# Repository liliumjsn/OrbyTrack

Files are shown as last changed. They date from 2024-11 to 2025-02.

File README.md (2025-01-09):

<p align="center">
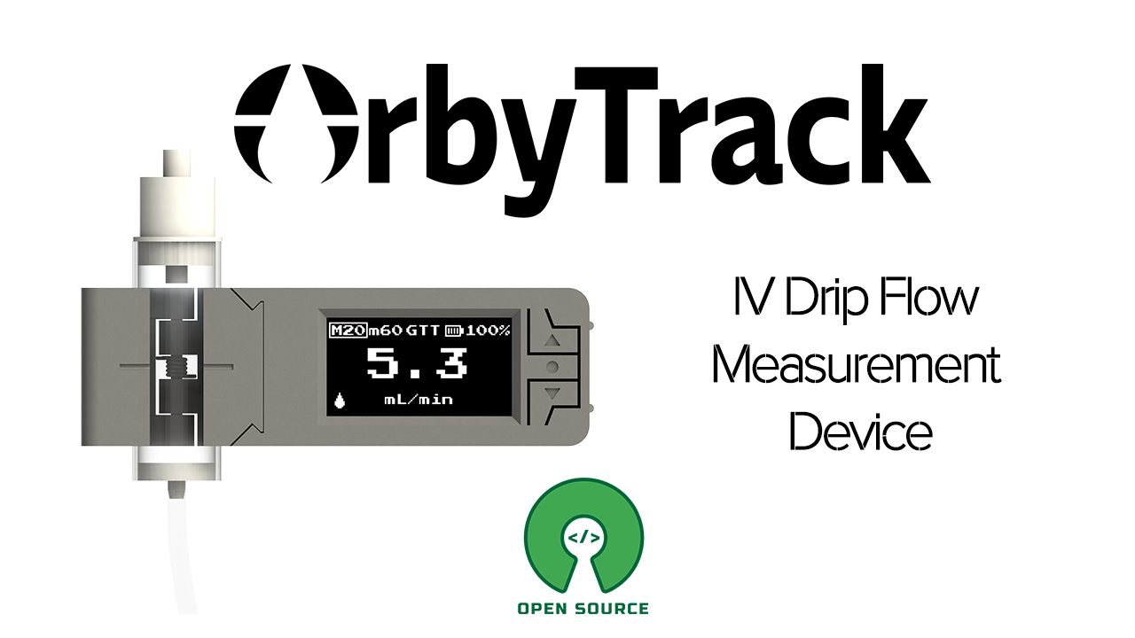
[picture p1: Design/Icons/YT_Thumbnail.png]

</p>

  
  

**OrbyTrack** is a portable, battery-operated device designed to measure the flow rate of an IV drip. Built using the Adafruit Feather M0 module, Adafruit OLED (128x64), and IR-based emitter-receiver drop detection, it provides healthcare professionals with a compact and efficient solution. For nurses working in high-pressure environments such as intensive care units or emergency rooms, OrbyTrack ensures accurate, real-time monitoring of IV flow rates. This accuracy is vital in life-critical moments, helping to prevent over-infusion or under-infusion of fluids, which could have severe consequences for patient outcomes. By providing clear and precise data, OrbyTrack empowers nurses to make informed decisions swiftly and confidently, ensuring patient safety remains the top priority. 

## Features  

- **Accurate Flow Measurement:** IR-based technology for precise IV drip monitoring.  
- **Portable and Battery-Operated:** With 500mAh battery, it can provide 20 hours of continuous usage.  
- **User-Friendly Interface:** Simple control with three tactile buttons and visible screen.  
- **Customizable:** Fully 3D-printable casing.  

## Project Structure  

```markdown
OrbyTrack/  
│  
├── Firmware/     # Codebase for Adafruit Feather M0  
├── Design/       # 3D design files for the casing  
├── Assembly/     # Step-by-step assembly instructions  
└── Usage/        # User guide, calibration, and troubleshooting 
```

## Hardware Overview  

| **Component** | **Details** |  
|---|---|
| Microcontroller | Atmel SAMD21 |  
| Module | Adafruit M0 | 
| Display | Adafruit OLED (128x64) |  
| Buttons | 3 tactile buttons |  
| Sensors | IR emitter-receiver  |  
| Power Source | Battery-operated (500mAh) |  

## License  

This project is licensed under the MIT License. See the `LICENSE` file for details.

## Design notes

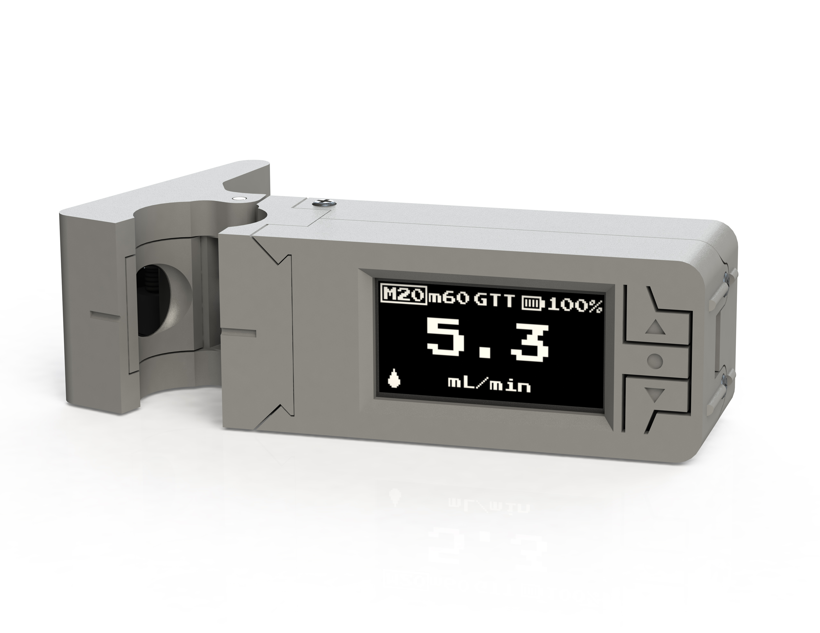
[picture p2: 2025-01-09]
Design/Renders/render_3.jpg

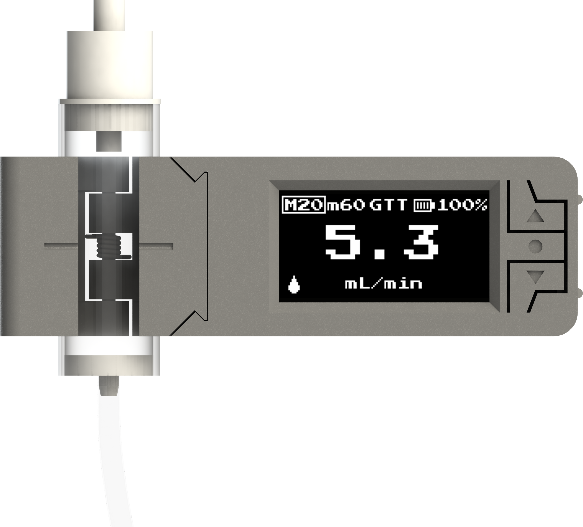
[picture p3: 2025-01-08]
Design/Renders/render_1.png

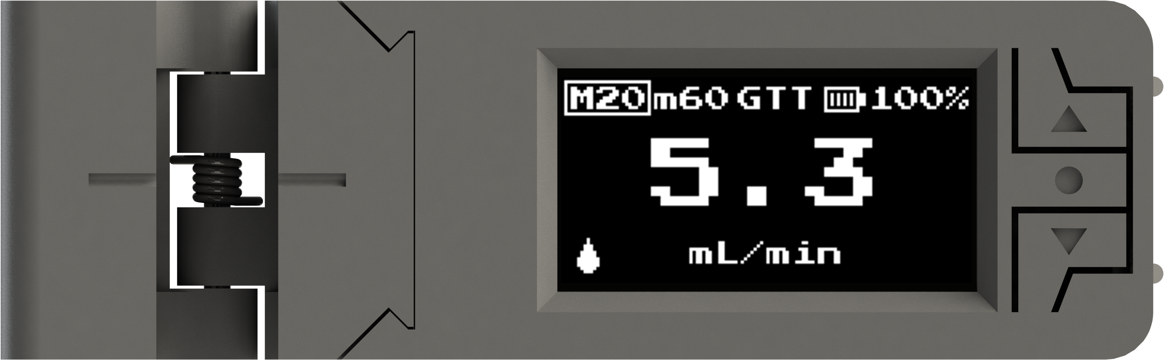
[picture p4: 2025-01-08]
Design/Renders/render_2.png

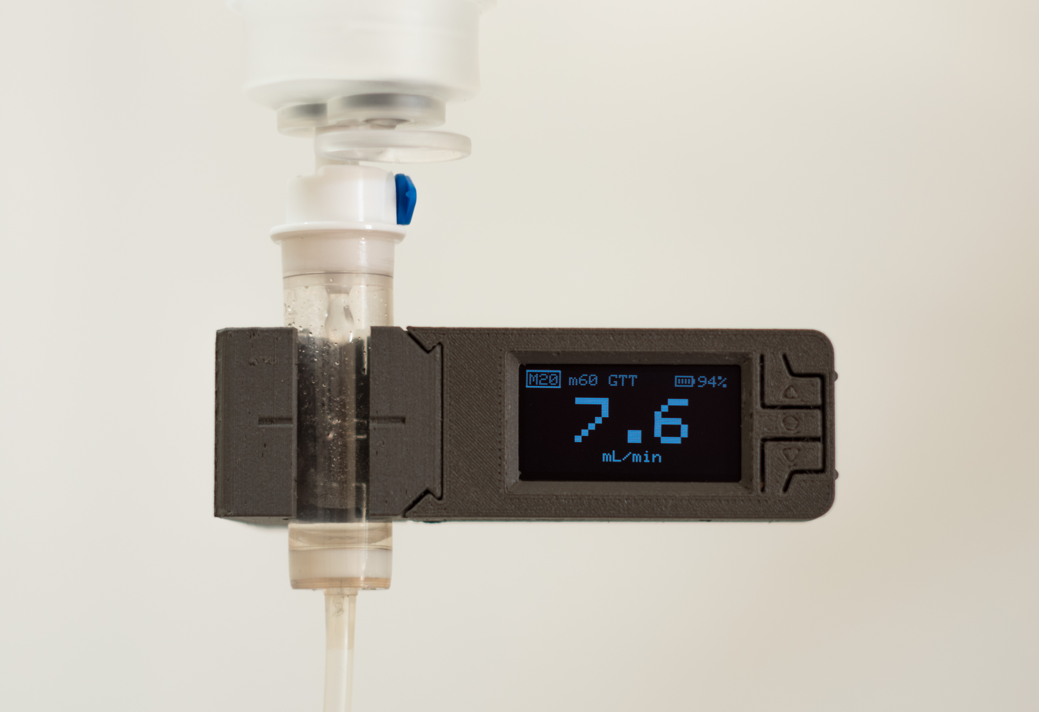
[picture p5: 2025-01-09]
Design/Photos/_JSN9351.jpg

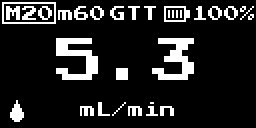
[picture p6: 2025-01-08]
Design/Renders/OrbyTrack Main Screen.png

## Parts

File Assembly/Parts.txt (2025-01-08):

3D Printed
- 1x clip_back_face_left
- 1x clip_back_face_right
- 2x clip_front_face
- 1x screen_back
- 1x screen_front

Electronics
- 1x Adafruit FeatherWing OLED - 128x64 OLED
- 1x Adafruit Feather M0/Adalogger
- 1x PT19-21B IR transistor 0603 package (https://www.aliexpress.com/item/1005005316682998.html)
- 1x 940NM (18-20mW) SMD IR LED 1.3-1.5v 20mA 0603 package (https://www.aliexpress.com/item/1005007587334171.html)
- 1x Lithium Battery, Length 48mm, Thickness 4mm, Width 20mm, 500mAh

Mechanical
- 2x IR Filter Disk, diameter 10mm, thickness 2mm
- 4x Screws, M1.7, 5mm

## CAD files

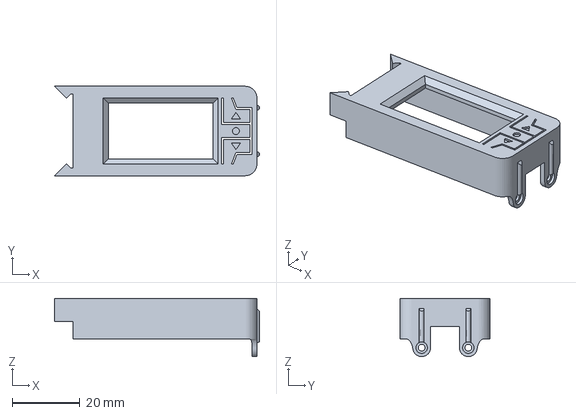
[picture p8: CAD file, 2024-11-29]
Design/3D Files/screen_front.3MF
60.7 x 26.5 x 17.2 mm

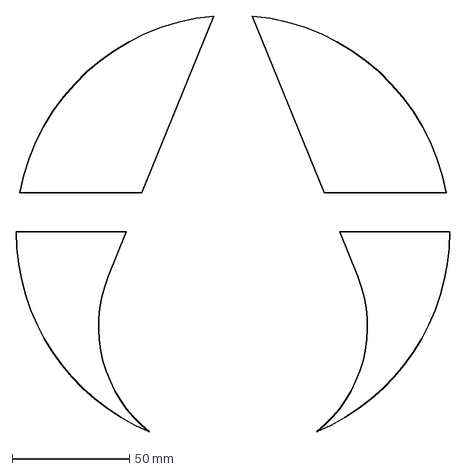
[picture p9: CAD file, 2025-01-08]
Design/Icons/OrbyTrack_logo.DXF
184.8 x 177.3 mm

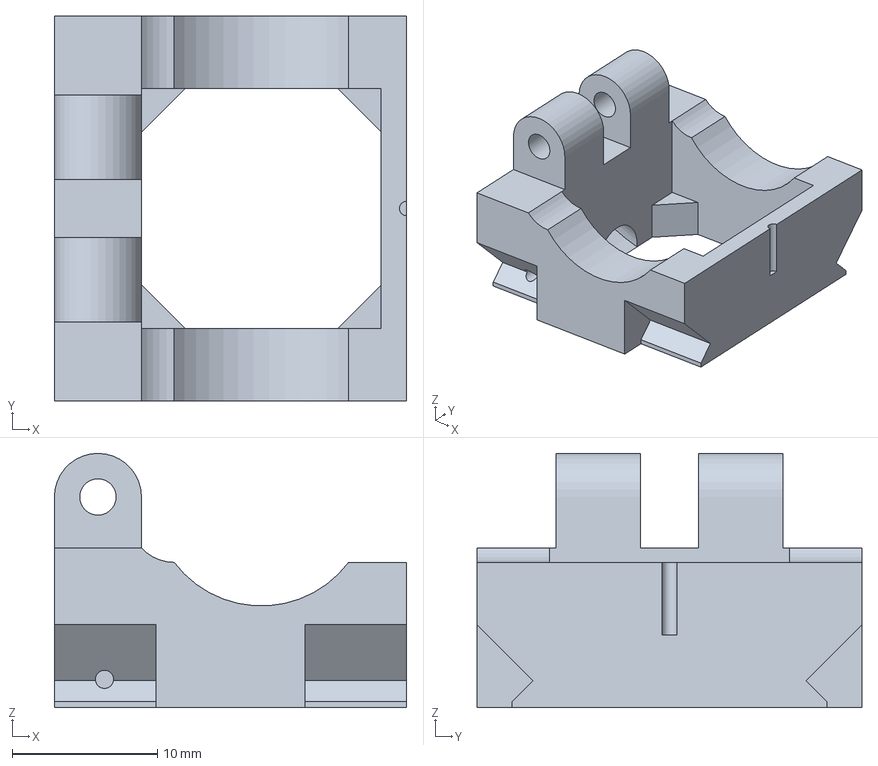
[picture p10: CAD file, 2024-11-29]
Design/3D Files/clip_back_face_right.3MF
24.3 x 26.5 x 17.5 mm

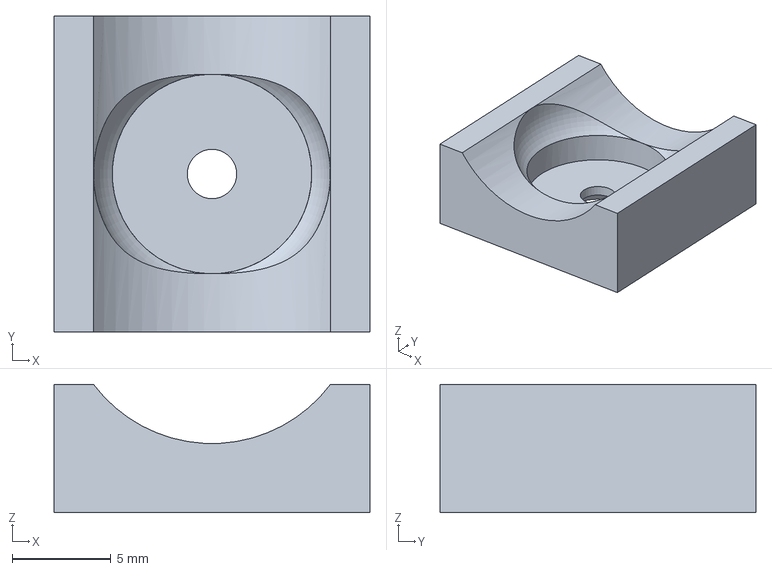
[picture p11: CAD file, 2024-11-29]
Design/3D Files/clip_front_face.3MF
16.0 x 16.0 x 6.50 mm

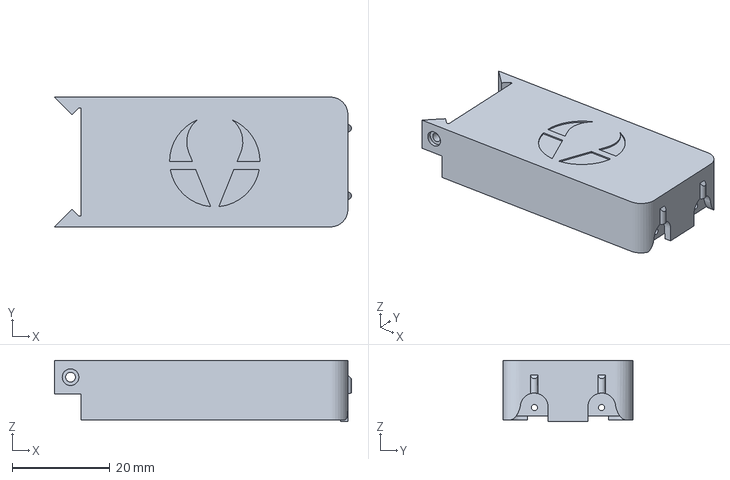
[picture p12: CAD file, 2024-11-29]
Design/3D Files/screen_back.3MF
60.7 x 26.5 x 12.6 mm

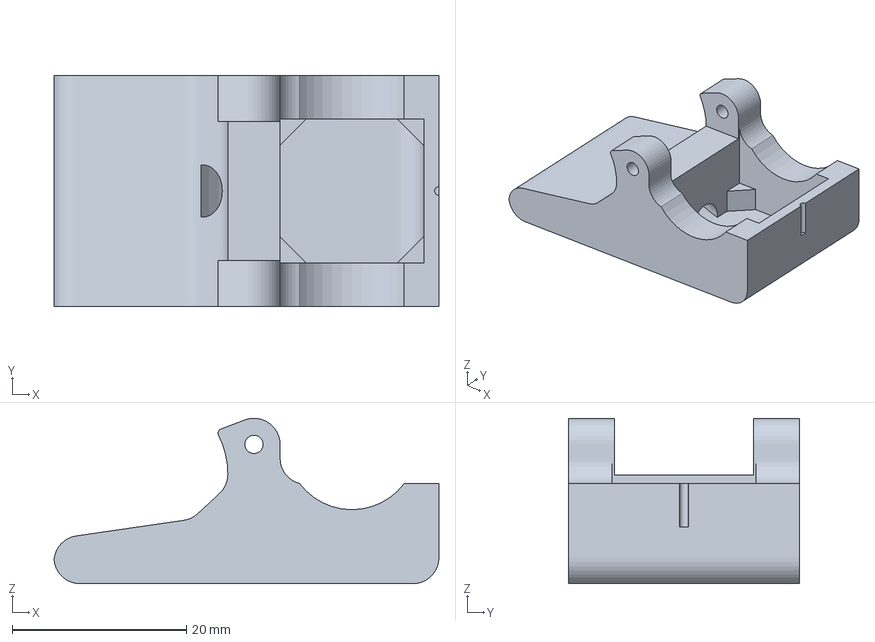
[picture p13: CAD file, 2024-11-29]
Design/3D Files/clip_back_face_left.3MF
44.2 x 26.5 x 19.0 mm

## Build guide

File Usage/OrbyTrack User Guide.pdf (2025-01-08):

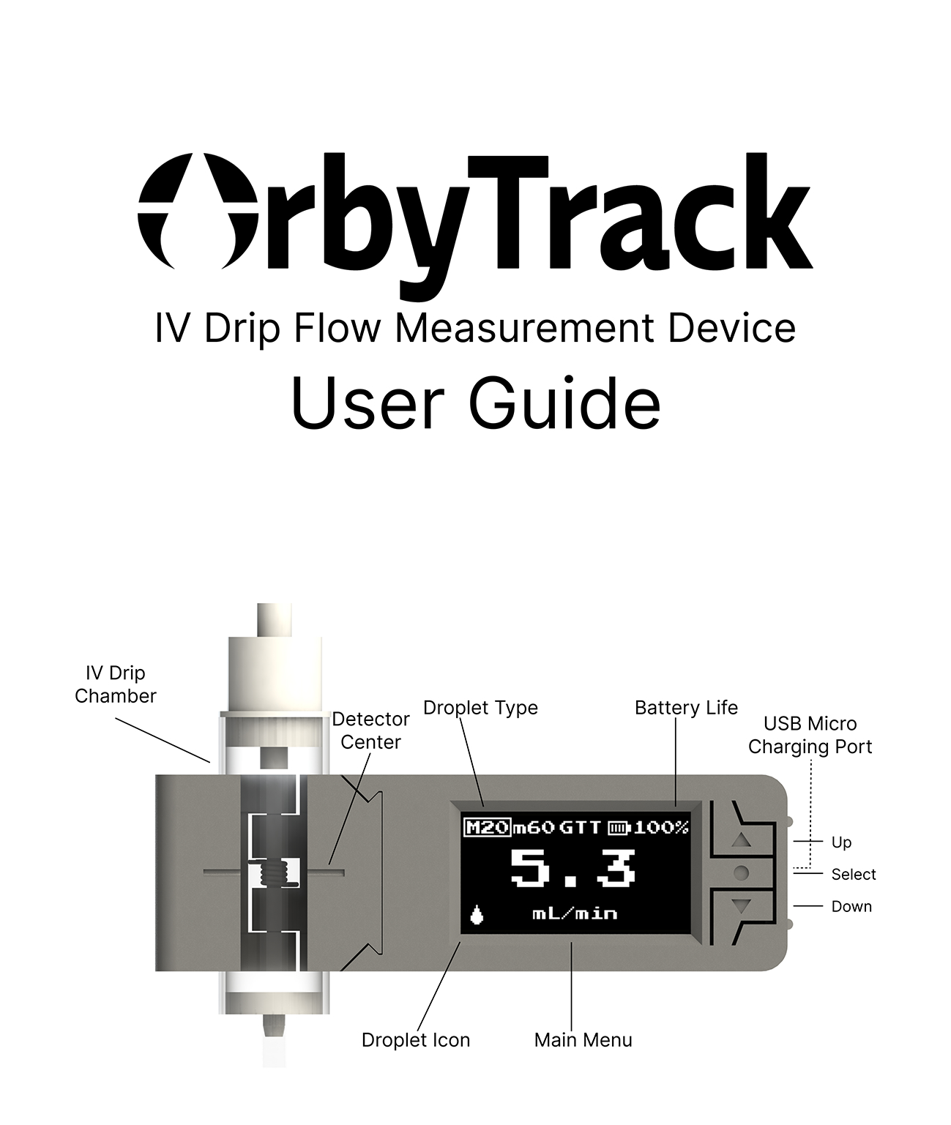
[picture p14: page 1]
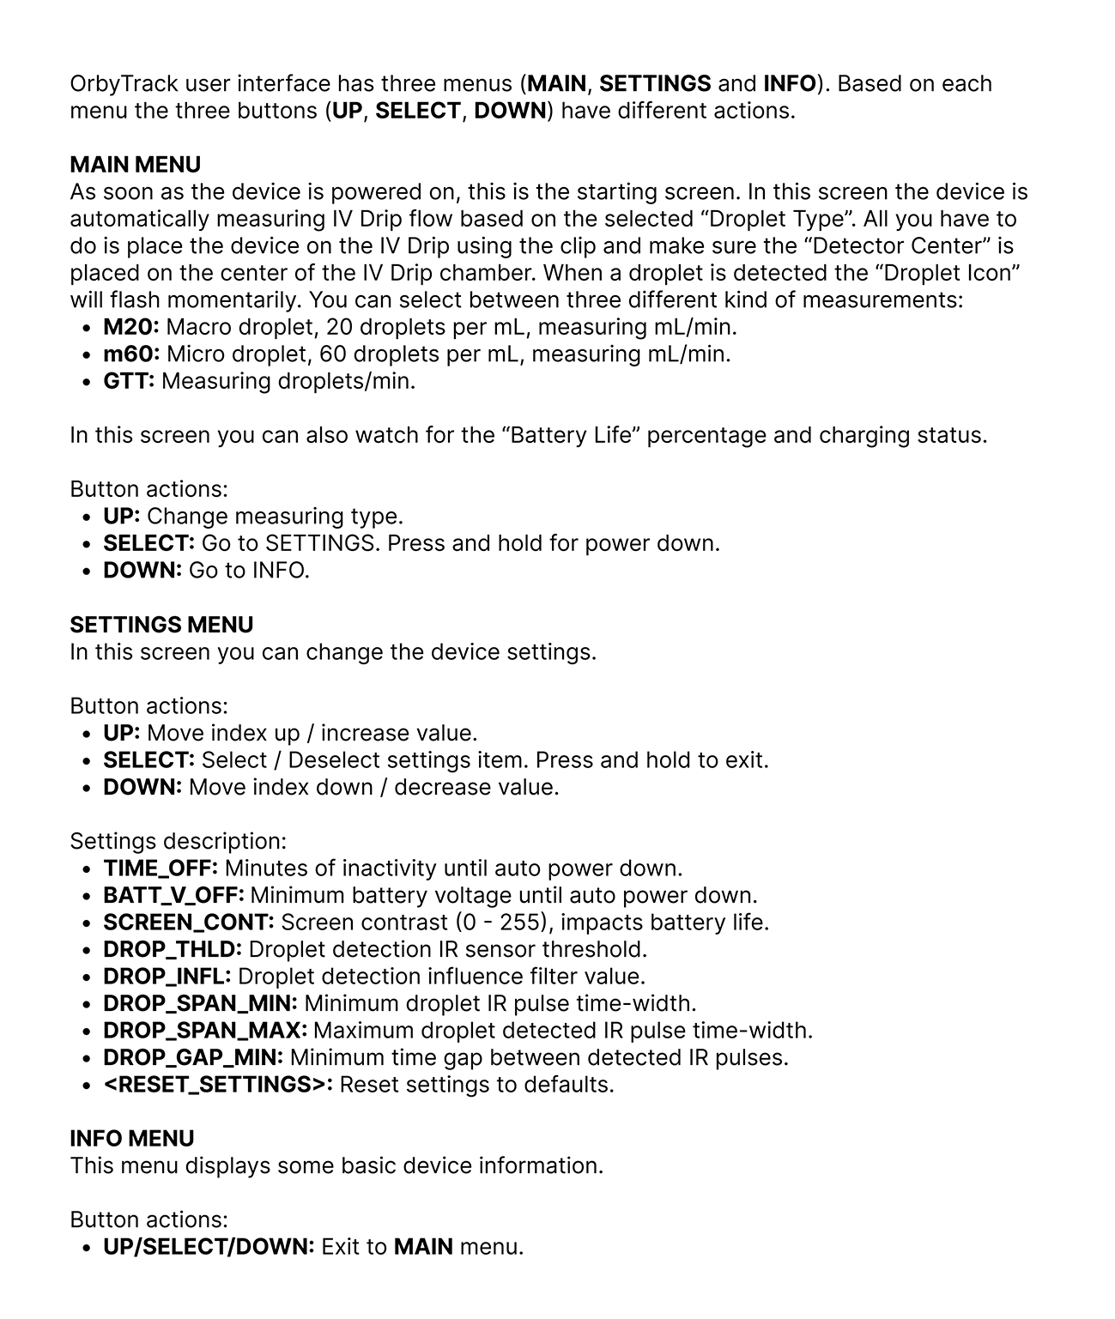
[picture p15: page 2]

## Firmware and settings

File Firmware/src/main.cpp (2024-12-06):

#include <Arduino.h>
#include "droplet_detector.h"
#include "ui_common.h"
#include "power_manager.h"
#include "pinout.h"
#include "settings.h"

void setup()
{
	Serial.begin(115200);
    delay(5000); // Making sure it doesn't get stuck in sleep without USB
    Serial.print("OrbyTrack ");
    Serial.print(ORBYTRACK_APP_VERSION);
    Serial.println(" by LiliumJSN");
    Settings::init();
    PowerManager::init();
    DropletDetector::init();
    DropletDetector::set_detection_cb([](DropletDetector::DetectedDroplet *latest_detected_droplet){
        PowerManager::reset_sleep_timer();
        Serial.println("DP");
        UiStateMain::droplet_detected_handler();
    });
    UiCommon::init();
}

void loop()
{
	PowerManager::handle();
    UiCommon::handle();
    PowerManager::SleepReason sleep_reason = PowerManager::is_time_to_sleep();
    switch(sleep_reason)
    {
        case PowerManager::SleepReason::NONE:
            break;
        case PowerManager::SleepReason::LOW_BAT:
            UiCommon::shutdown("LOW BATTERY");
            break;
       case PowerManager::SleepReason::INACTIVITY:
            UiCommon::shutdown("INACTIVITY");
            break;
    }
    DropletDetector::handle();
}

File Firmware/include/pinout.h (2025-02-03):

#ifndef PINOUT_H
#define PINOUT_H

#include "common.h"

const int PIN_IR_PT = PIN_A2;
const int PIN_IR_PT_EN = 10;
const int PIN_IR_LED = 12;
const int PIN_CHG = PIN_A1;
const int PIN_USB = 13;
const int PIN_BAT_LVL = PIN_A7;
const int PIN_OLED_PANEL_EN = PIN_A0;
const int PIN_BTN_UP = 5;
const int PIN_BTN_OK = 6;
const int PIN_BTN_DN = 11;

#endif

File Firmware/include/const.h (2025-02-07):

#ifndef CONST_H
#define CONST_H

#include "common.h"

#define ORBYTRACK_APP_VERSION "v2.1"

const int SCREEN_WIDTH = 128;  // OLED display width, in pixels
const int SCREEN_HEIGHT = 64; // OLED display height, in pixels

const float CHG_FLOATING_MAX = 3.1f;
const float CHG_FLOATING_MIN = 0.5f;
const float BATT_VOLT_INFLUENCE = 0.05f;
const float BATT_PERC_INFLUENCE = 0.05f;

const size_t PT_READ_BUFF_SIZE = 150;
const uint16_t PT_TIMER_INTERVAL_US = 100;
const uint16_t PT_SAMPLING_INTERVAL_US = 10 * PT_TIMER_INTERVAL_US;
const uint16_t DROPLET_PERIOD_MAX_SEC = 120;

const uint16_t BOOT_LOGO_DURATION_MS = 7000;
const uint16_t WAKEUP_LOGO_DURATION_MS = 4000;
const uint16_t SLEEP_LOGO_DURATION_MS = 3000;
const uint8_t DISPLAY_I2C_ADDR = 0x3C;
const uint16_t DISPLAY_REF_PERIOD_MS = 1000;

const uint32_t STORAGE_MAGIC_BYTES_VALAUE = 0xA55B00B5;

const uint16_t DROPLEPT_INDICATOR_BLINK_DURATION_MS = 150;

const uint8_t SETTINGS_ITEMS_PER_PAGE = 5;

const uint8_t DROPLET_MACRO_PER_ML = 20;
const uint8_t DROPLET_MICRO_PER_ML = 60;

const uint16_t MIN_BOOT_TIME_BEFORE_LOW_BATT_OFF_MS = 50000;

#endif

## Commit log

2024-11-29 Modded screen pads afraid of screen crack
    [screen_front.3MF]
2024-12-06 Detector influence filter fix
    [droplet_detector.cpp]
2024-12-06 Battery percentage fixes
2024-12-06 Settings reset to default feature
    [settings.cpp]
2025-01-08 Design files
    [OrbyTrack_logo.DXF, clip_back_face_left.3MF, clip_back_face_right.3MF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]
2025-02-03 Sample values as bg percentage to compensate sunlight
2025-02-03 Fixed interval handling and changed period
    [const.h, droplet_detector.cpp]

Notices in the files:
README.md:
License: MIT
